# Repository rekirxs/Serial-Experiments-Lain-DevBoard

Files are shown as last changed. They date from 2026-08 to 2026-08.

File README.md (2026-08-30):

# Serial-Experiments-Lain-DevBoard

let's all love lain.

A custom ESP32-C3 dev board built as a appreciation  to Serial Experiments Lain. Not a Lain branded case for a stock dev board  this is a from-scratch PCB with its own connector layout, onboard RGB status LED, and just enough buttons to feel like a piece of hardware from the Wired.

Also I just wanted an excuse to build a PCB.

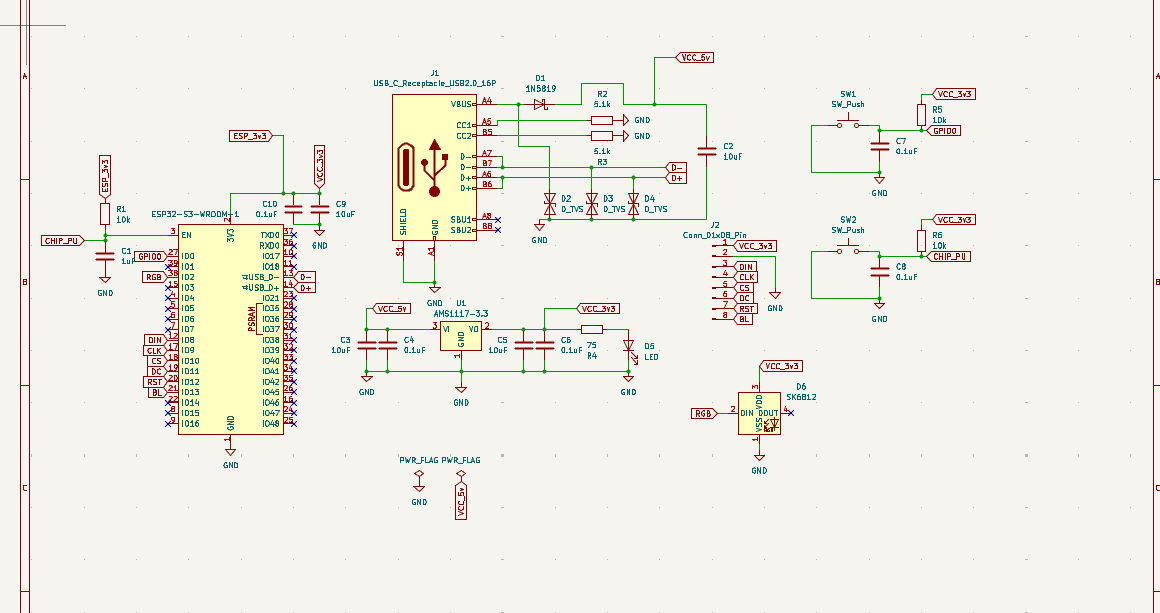
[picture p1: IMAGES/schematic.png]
schematic


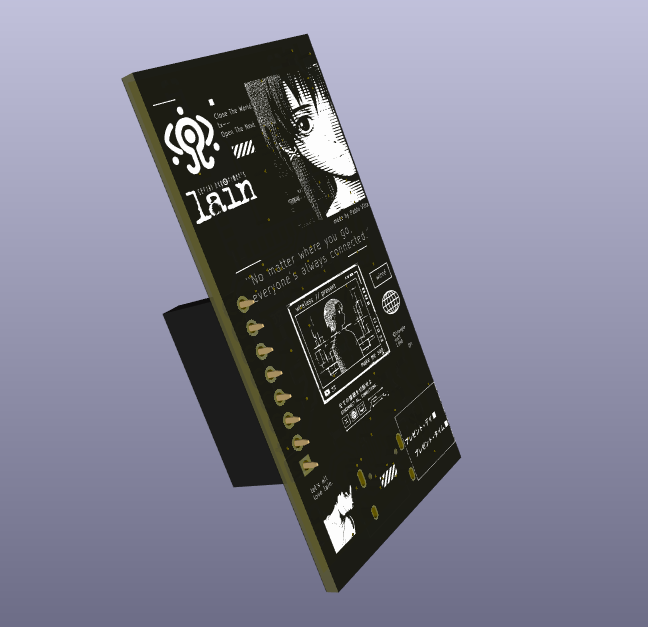
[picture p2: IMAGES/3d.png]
3d


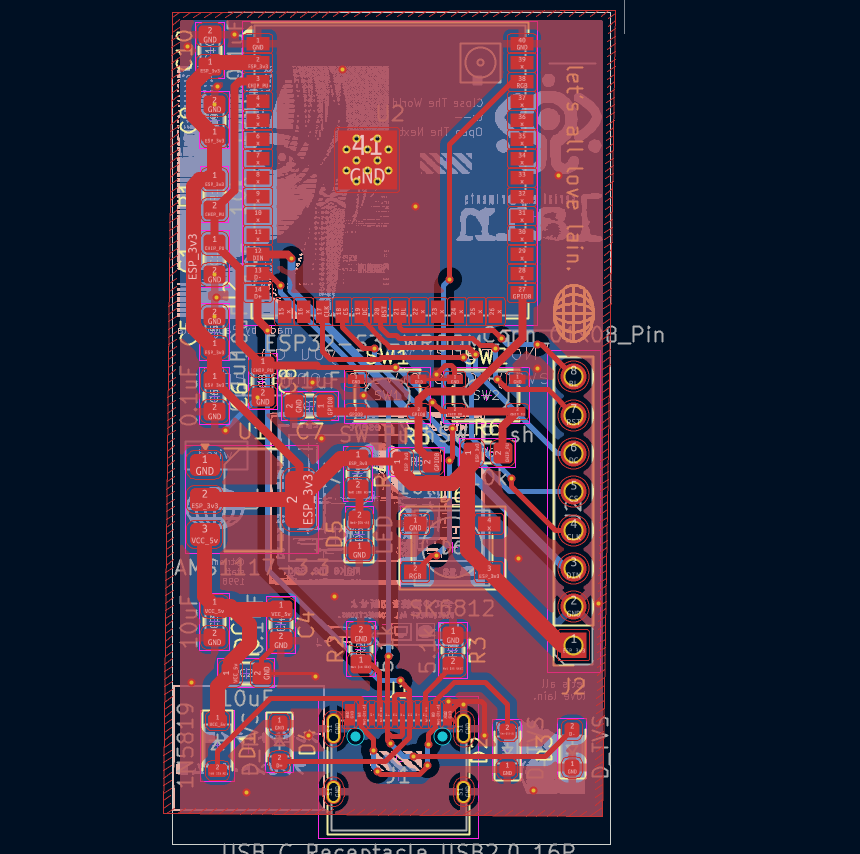
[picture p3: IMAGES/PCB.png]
PCB


Hardware
MCU: ESP32-C3 — WiFi/BLE, RISC-V single-core, low power draw for anything battery-powered
USB-C: native USB-C receptacle (16-pin), no more digging through a drawer for the right cable
Status LED: onboard SK6812 addressable RGB — Present indicator, whatever color the Wired feels like that day
Buttons: 2x SMD tactile switches, low-profile, doesn't add bulk to the silhouette
Power: 3.3V regulated, USB-powered or battery-ready depending on the build

Full BOM and sourcing notes live in /hardware.

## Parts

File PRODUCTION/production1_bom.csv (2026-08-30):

Designator | Footprint | Quantity | Value | LCSC Part #
C1 | 0805 | 1 | 1uF
C10, C4, C6, C7, C8 | 0805 | 5 | 0.1uF
C2, C3, C5, C9 | 0805 | 4 | 10uF
D1 | D_SOD-123 | 1 | 1N5819
D2, D3, D4 | D_SOD-323_HandSoldering | 3 | D_TVS
D5 | 0805 | 1 | LED
D6 | LED_SK6812_PLCC4_5.0x5.0mm_P3.2mm | 1 | SK6812
J1 | USB_C_Receptacle_HRO_TYPE-C-31-M-12 | 1 | USB_C_Receptacle_USB2.0_16P
J2 | PinSocket_1x08_P2.54mm_Vertical | 1 | Conn_01x08_Pin
R1, R5, R6 | 0805 | 3 | 10k
R2, R3 | 0805 | 2 | 5.1k
R4 | 0805 | 1 | 75
SW1, SW2 | SW_SPST_PTS810 | 2 | SW_Push
U1 | SOT-223-3_TabPin2 | 1 | AMS1117-3.3
U2 | ESP32-S3-WROOM-1U | 1 | ESP32-S3-WROOM-1

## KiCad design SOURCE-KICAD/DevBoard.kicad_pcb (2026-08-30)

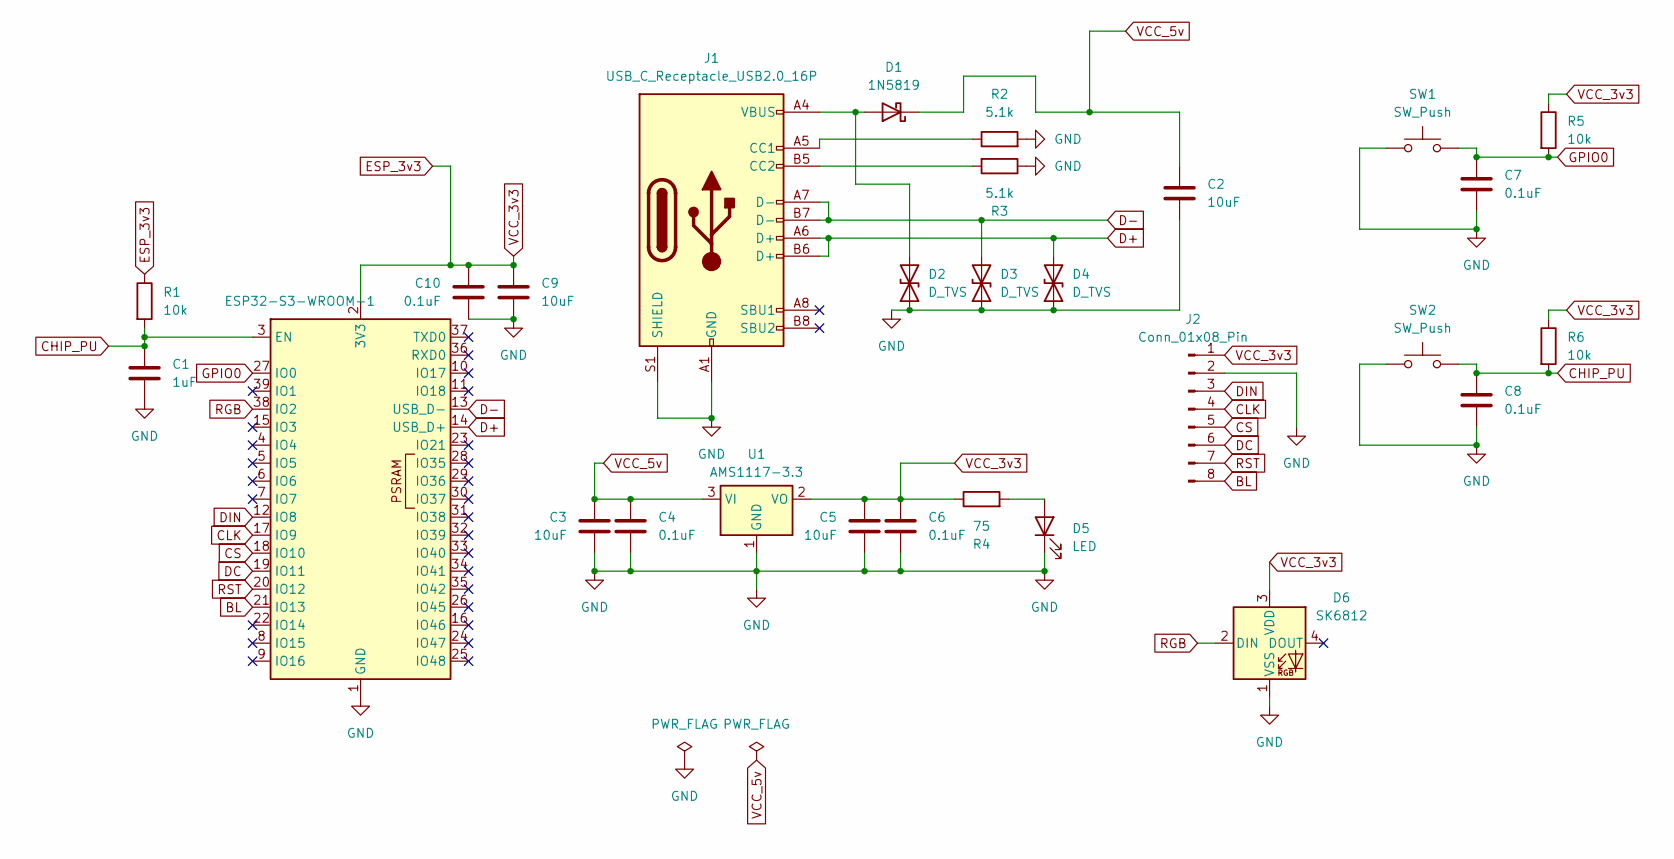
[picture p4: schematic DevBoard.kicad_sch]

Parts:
C1: 1uF; C_0805_2012Metric_Pad1.18x1.45mm_HandSolder
C2, C3, C5, C9: 10uF; C_0805_2012Metric_Pad1.18x1.45mm_HandSolder
C4, C6, C7, C8, C10: 0.1uF; C_0805_2012Metric_Pad1.18x1.45mm_HandSolder
D1: 1N5819; D_SOD-123
D2, D3, D4: D_TVS; D_SOD-323_HandSoldering
D5: LED; LED_0805_2012Metric_Pad1.15x1.40mm_HandSolder
D6: SK6812; LED_SK6812_PLCC4_5.0x5.0mm_P3.2mm
J1: USB_C_Receptacle_USB2.0_16P; USB_C_Receptacle_HRO_TYPE-C-31-M-12
J2: Conn_01x08_Pin; PinSocket_1x08_P2.54mm_Vertical
R1, R5, R6: 10k; R_0805_2012Metric_Pad1.20x1.40mm_HandSolder
R2, R3: 5.1k; R_0805_2012Metric_Pad1.20x1.40mm_HandSolder
R4: 75; R_0805_2012Metric_Pad1.20x1.40mm_HandSolder
SW1, SW2: SW_Push; SW_SPST_PTS810
U1: AMS1117-3.3; SOT-223-3_TabPin2
U2: ESP32-S3-WROOM-1; ESP32-S3-WROOM-1U

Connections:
BL: J2.8, U2.21 (IO13)
CHIP_PU: C1.1, C8.1, R1.2, R6.2, SW2.2, U2.3 (EN)
CLK: J2.4, U2.17 (IO9)
CS: J2.5, U2.18 (IO10)
D+: D4.2 (A2), J1.A6 (D+), J1.B6 (D+), U2.14 (USB_D+)
D-: D3.2 (A2), J1.A7 (D-), J1.B7 (D-), U2.13 (USB_D-)
DC: J2.6, U2.19 (IO11)
DIN: J2.3, U2.12 (IO8)
ESP_3v3: C5.1, C6.1, C9.1, C10.1, D6.3 (VDD), J2.1, R1.1, R4.1, R5.1, R6.1, U1.2 (VO), U2.2 (3V3)
GND: C1.2, C2.2, C3.2, C4.2, C5.2, C6.2, C7.2, C8.2, C9.2, C10.2, D2.1 (A1), D3.1 (A1), D4.1 (A1), D5.1 (K), D6.1 (VSS), J1.A1 (GND), J1.A12 (GND), J1.B1 (GND), J1.B12 (GND), J1.S1 (SHIELD), J2.2, R2.2, R3.1, SW1.1, SW2.1, U1.1 (GND), U2.1 (GND), U2.40 (GND), U2.41 (GND)
GPIO0: C7.1, R5.2, SW1.2, U2.27 (IO0)
unnamed: D1.2 (A), D2.2 (A2), J1.A4 (VBUS), J1.A9 (VBUS), J1.B4 (VBUS), J1.B9 (VBUS)
unnamed: D5.2 (A), R4.2
unnamed: J1.A5 (CC1), R2.1
unnamed: J1.B5 (CC2), R3.2
RGB: D6.2 (DIN), U2.38 (IO2)
RST: J2.7, U2.20 (IO12)
VCC_5v: C2.1, C3.1, C4.1, D1.1 (K), U1.3 (VI)

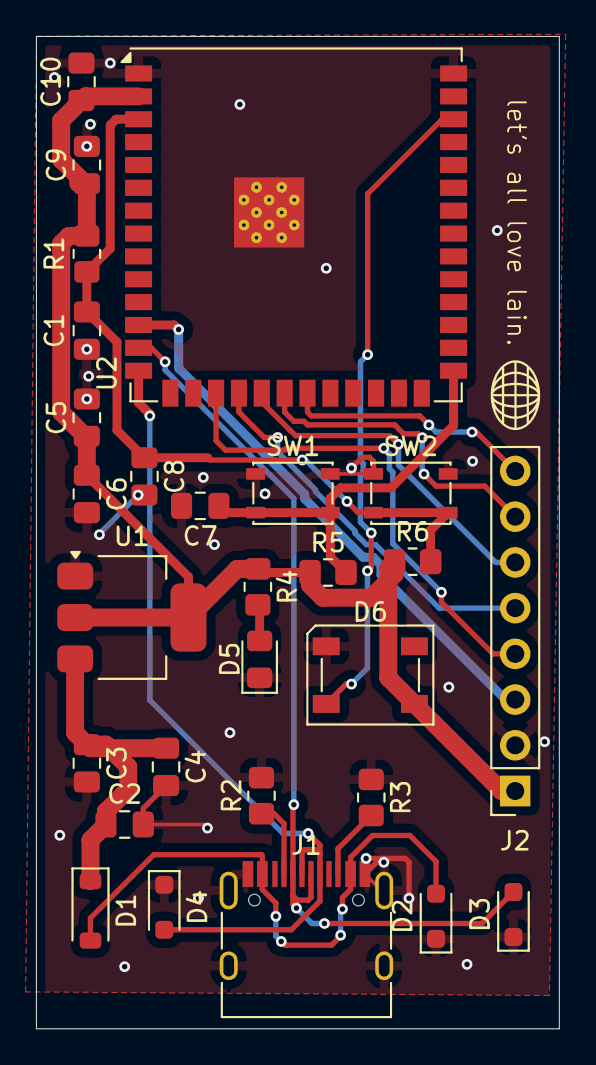
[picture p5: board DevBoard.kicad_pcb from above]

Board: 2 copper layers, 29.0 x 55.1 mm, 28 parts (0 on the bottom side), 18 nets.

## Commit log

2026-08-30 Revise prices in production1_shopping_list.csv
    Updated prices for various components in the shopping list.
    [production1_shopping_list.csv]
2026-08-30 Update AMS1117-3.3V price and add purchase link
    Updated the price of AMS1117-3.3V (SOT-223) and added a link.
    [production1_shopping_list.csv]
2026-08-30 Fix duplicate entry for SK6812 RGB LED
    [production1_shopping_list.csv]
2026-08-30 Delete obsolete items from BOM - MACONDO
    Removed outdated BOM items and links.
    [BOM - MACONDO - Hoja 1.csv]
2026-08-30 Add BOM to production1_shopping_list.csv
2026-08-30 Correct image caption from 'pcb' to 'PCB'
2026-08-30 Fix image filename case for PCB in README

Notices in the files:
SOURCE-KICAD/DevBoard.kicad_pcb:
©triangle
